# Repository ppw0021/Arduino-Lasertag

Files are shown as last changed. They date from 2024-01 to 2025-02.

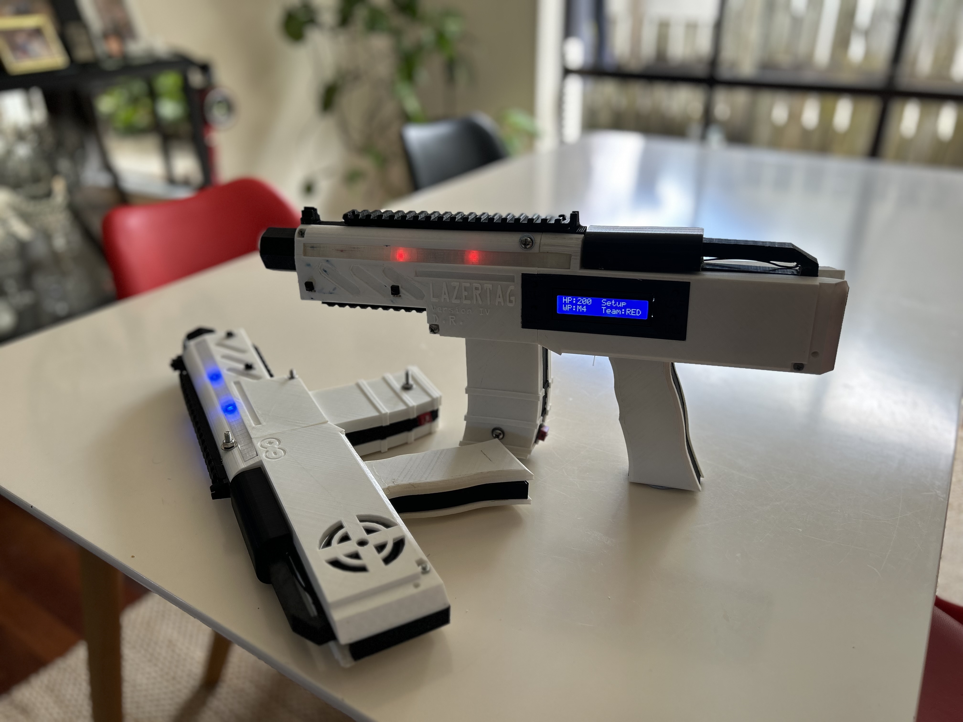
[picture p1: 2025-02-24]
Guns.jpg

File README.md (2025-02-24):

# DIY Arduino Lasertag

This is an Arduino powered Infrared laser tag set I created. It is powered using an Arduino Nano. The set has 6 primary functions and features such as, ammunition counter, hit-detection from other laser tag guns, IR data analysis, reloading button paired with a slider, LCD user interface and finally a play feedback subsystem as well as features such as 8 different weapons, filtration of teamfire and a health counter. This project scored me a spot at the ASB Brightsparks competition.

Guns

## 3D printed parts
Each laser tag gun consists of 13 3D printed parts. The guns structure uses a middle black frame which holds a majority of the electronic components and microcontroller, while 4 large shells cover both sides of the black frame.

Frame:

FrameRender

Exploded assembly:

FullRenderExploded

Frame with shells and accessories:

FullRender

As this was a long time and I did not know any better, I created the 3D models in SketchUp (🤮) and exported them as very very broken STLs. I used Netfabb to fix the models and make them manifold.
I recommend using Black, White and Clear PLA or ABS plastic at 0.1mm layer height for best results. 

## Electronics

The microcontroller for this project is an Arduino Nano with an ATmega328p chip onboard.
The following components are required for each laser gun:
- 1x IR LED  (For signal transmission)
- 1x 31MM biconvex lens 27MM focal point  (For straightening the IR light from the IR LED)
- 6x IR Receiver TSOP4838 DIP3  (For receiving transmissions from other laser guns)
- 1x i2c 16x2 LCD display modules  (For displaying UI to user)
- 1x YX5300 UART Serial MP3 player  (For playing sounds)
- 1x MicroSD card  (For storing sounds)
- 3x DC3v Button Vibrating Motors  (For providing haptic feedback)
- 6x push buttons  (For navigating UI and reload switches)
- 1x PAM8403 digital amplifier (For amplifying the audio signal from the MP3 Player)
  - 1x 4omh speaker
  - 1x 4.7uF capacitor
- 7x 1k ohm resistors (Various pulldown)
- 1x NPN transistor (For switching on and off the vibrating motors)

## Assembly of Electronics

The wiring and connections for each gun is shown below.

Layout

With the wiring and assembly completed, this is how each device looks.





## Biconvex lens

A biconvex lens is required to convert the dispersed light from the IR led into collimated light. (Basically straightening out the light rays) This is required so that the light behaves similarly to a 'bullet' and travels in a straight line, allowing for an accurate simulation.

lens with lines

## Code

```cpp
/***********************************************************/
//  Program made by Declan Ross
//  26,08,2018
//  V3.1
//
//
//    MP3:
//    sendSong(CMD_PLAY_W_VOL, 0x1E, 0x02);     Replace 0x02 with Hex MP3 name, use this for playing files
//                                              Also, 0x1E can be replaced with a volume Hex number (0-30)
//                                              0x1E=30
//
//
//    ammoQuota = checkAmmo(wpSL);              Use these 2 lines of code to refresh the display
//    lcdPrintPL(hpSL, ammoLeft, wpSL, tmSL);
//
//    ammoLeft=ammoQuota;                       Use this one to reload
//
//    Use pause() instead of delay() so that interupts will work
//
//
//    USE THE MAIN DIRECTORY FOR IMPORTANT TIMING ON THE SD CARD
//    MP3's IN A FOLDER TAKE LONGER TO EXECUTE
//
//
//    Use function pauseIR() instead of delays so that the arduino can recieve singals
//    and pause at the same time
//
//    pauseIR(500, tmSL, hpSL);
//
//    //USE THIS LINE TO CHECK IRIN SIGNAL
//    checkIRIN(tmSL, hpSL);
//
//
//
//
//
/***********************************************************/

/***********************************************************/
//For easy customisation change values
//
//
#define m4dmg 35
#define smgdmg 21
#define uspdmg 40
#define awpdmg 75
#define m4sdmg 30
#define smgsdmg 19
#define uspsdmg 38
#define awpsdmg 70

//MP3 custom lib
static int8_t Send_buf[8] = {0} ;
#define CMD_PLAY_W_INDEX 0X03
#define CMD_SET_VOLUME 0X06
#define CMD_SEL_DEV 0X09
#define DEV_TF 0X02
#define CMD_PLAY 0X0D
#define CMD_PAUSE 0X0E
#define CMD_SINGLE_CYCLE 0X19
#define SINGLE_CYCLE_ON 0X00
#define SINGLE_CYCLE_OFF 0X01
#define CMD_PLAY_W_VOL 0X22
#define CMD_PLAY_IN_FOLDER 0X0F

//Include The folowing Libraries
//LCD req
#include <LiquidCrystal_I2C.h>
#include <IRremote.h>
#include <SoftwareSerial.h>
#include <Wire.h>

//IR req
//Experimental

//Working
//#include <IRLibDecodeBase.h>
//#include <IRLibSendBase.h>
//#include <IRLib_P01_NEC.h>
//#include <IRLib_P02_Sony.h>
//#include <IRLib_HashRaw.h>  //Must be last protocol
//#include <IRLibCombo.h>
//#include <IRLibRecv.h>
//MP3 Req

//Define logical pins to words
#define fireTrigger 7
#define irIn 2
#define magReload 4
#define vMotor 5
#define lowHP 6
#define irOut 3
#define ARDUINO_RX A6
#define ARDUINO_TX 8
SoftwareSerial mySerial(ARDUINO_RX, ARDUINO_TX);
#define tmBluLED 9
#define tmRedLED 10
//#define fireMode 11
#define slideSW 12
#define hpSW A7
#define ST1LED 17
#define ST2LED 16
#define tmSW 15
#define wpSW 14
#define confSW 13

//Millis timer functionality
unsigned long startMillis;  //some global variables available anywhere in the program
unsigned long currentMillis;

//Set integers
int setConfirmed;
int displayCountdown;
boolean alive;
int timerBreak;
unsigned long pauseT;
unsigned long gunSound;
unsigned long hexCode;
int pauseTime;
boolean slideDone;
boolean oof;
int dmgM;
long unsigned longValue;

//Set button state variables
boolean rlST;
boolean sldST;
boolean trST;
boolean tmST;
boolean wpST;
int hpST;
boolean confST;
boolean slideST;
boolean btnPressed;

//Set selected state veriables
int tmSL;
int wpSL = 0;
int hpSL; //This also doubles as current hp

//Weapon variables
int ammoQuota;
int ammoLeft;

//Define others
//LiquidCrystal_I2C lcd(0x27, 2, 1, 0, 4, 5, 6, 7, 3, POSITIVE);
LiquidCrystal_I2C lcd(0x27,20,4);
IRrecv irrecv(2);
decode_results results;
IRsend irsend;

//IRrecv myReceiver(2);
//IRdecode myDecoder;
//IRsend mySender;

void setup() {
  startMillis = millis();
  pinMode(tmBluLED, OUTPUT);
  pinMode(tmRedLED, OUTPUT);   // start serial interface
  pinMode(ST1LED, OUTPUT);
  pinMode(ST2LED, OUTPUT);
  pinMode(vMotor, OUTPUT);
  pinMode(lowHP, OUTPUT);
  mySerial.begin(9600);
  pause(500);             // wait for init
  selectCommand(CMD_SEL_DEV, DEV_TF);   //select sd-card
  pause(500);         // wait for init
  lcd.begin(16, 2);
  pause(200);
  lcd.print("LAZERTAG beta3.1");
  lcd.setCursor(0, 1);
  lcd.print("Made by:Declan.R");
  pause(1000);
  lcd.clear();
  lcd.print("HP:     Setup   ");
  lcd.setCursor(0, 1);
  lcd.print("WP:     Team:   ");
  randomSeed(analogRead(6));
}

void loop() {
  while (setConfirmed == 0) {  //Setup code for setting variables, player cannot be hit and this should freeze when player clicks confirm.
    wpSL = wpSLfunc(wpSL);
    hpSL = hpSLfunc(hpSL);
    tmSL = tmSLfunc(tmSL);
    setConfirmed = confunc(setConfirmed);
  }

  if (displayCountdown == 0) {
    lcd.clear();
    lcd.print("Game starts in:");
    lcd.setCursor(7, 1);
    pause(200);
    lcd.print("3");
    sendSong(CMD_PLAY_IN_FOLDER, 0x02, 0x05);
    pause(400);
    lcd.setCursor(7, 1);
    lcd.print("2");
    sendSong(CMD_PLAY_IN_FOLDER, 0x02, 0x05);
    pause(400);
    lcd.setCursor(7, 1);
    lcd.print("1");
    sendSong(CMD_PLAY_IN_FOLDER, 0x02, 0x05);
    pause(400);
    lcd.setCursor(7, 1);
    lcd.print("GO!");
    sendSong(CMD_PLAY_IN_FOLDER, 0x02, 0x06);
    pause(400);
    displayCountdown = 1;
    ammoQuota = checkAmmo(wpSL);              //Use these 2 lines of code to refresh the screen
    ammoLeft = ammoQuota;
    lcdPrintPL(hpSL, ammoLeft, wpSL, tmSL);     //with the HP, TM, current AMMO and WP
    irrecv.enableIRIn();
  }
  while (alive == 0) {
    do {
      if (irrecv.decode(&results)) {        /// ADD THIS IF STATEMENT TO OTHER IR CHECKERS
        hpSL = checkIR(tmSL, hpSL, results.value);
        results.value = 0x00;
        if (hpSL == 0 or hpSL <= 0) {
          sendSong(CMD_PLAY_IN_FOLDER, 0x03, 0x02);
          deadLoop();
        }
        lcdUpdateHP(hpSL);
      }
      ammoQuota = checkAmmo(wpSL);
      trST = digitalRead(fireTrigger);
      if (trST == 1) {
        btnPressed = 1;
      }
      wpST = digitalRead(wpSW);
      if (wpST == 1) {
        btnPressed = 1;
      }
      rlST = digitalRead(magReload);
      if (rlST == 1) {
        btnPressed = 1;
      }
    } while (btnPressed == 0);
    if (wpST == 1) {
      wpSL = wpSLfunc2(wpSL);
      lcdPrintPL(hpSL, ammoLeft, wpSL, tmSL);
      ammoLeft = 0;
      lcd.setCursor(8, 0);
      lcd.print("RELOAD  ");
      btnPressed = 0;
    }
    if (rlST == 1) {
      lcd.setCursor(8, 0);
      lcd.print("RELOAD  ");
      lcd.setCursor(0, 1);
      lcd.print("Reloading       ");
      sendSong(CMD_PLAY_IN_FOLDER, 0x02, 0x07);   //play mag reload sound
      pause(70);
      digitalWrite(vMotor, HIGH);
      pause(150);
      if (irrecv.decode(&results)) {        /// ADD THIS IF STATEMENT TO OTHER IR CHECKERS
        hpSL = checkIR(tmSL, hpSL, results.value);
        results.value = 0x00;
        if (hpSL == 0 or hpSL <= 0) {
          sendSong(CMD_PLAY_IN_FOLDER, 0x03, 0x02);
          deadLoop();
        }
        lcdUpdateHP(hpSL);
      }
      digitalWrite(vMotor, LOW);
      pause(530);
      if (irrecv.decode(&results)) {        /// ADD THIS IF STATEMENT TO OTHER IR CHECKERS
        hpSL = checkIR(tmSL, hpSL, results.value);
        results.value = 0x00;
        if (hpSL == 0 or hpSL <= 0) {
          sendSong(CMD_PLAY_IN_FOLDER, 0x03, 0x02);
          deadLoop();
        }
        lcdUpdateHP(hpSL);
      }
      digitalWrite(vMotor, HIGH);
      pause(150);
      if (irrecv.decode(&results)) {        /// ADD THIS IF STATEMENT TO OTHER IR CHECKERS
        hpSL = checkIR(tmSL, hpSL, results.value);
        results.value = 0x00;
        if (hpSL == 0 or hpSL <= 0) {
          sendSong(CMD_PLAY_IN_FOLDER, 0x03, 0x02);
          deadLoop();
        }
        lcdUpdateHP(hpSL);
      }
      digitalWrite(vMotor, LOW);
      pause(500);
      if (irrecv.decode(&results)) {        /// ADD THIS IF STATEMENT TO OTHER IR CHECKERS
        hpSL = checkIR(tmSL, hpSL, results.value);
        results.value = 0x00;
        if (hpSL == 0 or hpSL <= 0) {
          sendSong(CMD_PLAY_IN_FOLDER, 0x03, 0x02);
          deadLoop();
        }
        lcdUpdateHP(hpSL);
      }
      slideDone = 0;
      while (slideDone == 0) {
        lcd.setCursor(0, 1);
        lcd.print("Slide to reload ");
        slideST = digitalRead(slideSW);
        if (irrecv.decode(&results)) {        /// ADD THIS IF STATEMENT TO OTHER IR CHECKERS
          hpSL = checkIR(tmSL, hpSL, results.value);
          results.value = 0x00;
          if (hpSL == 0 or hpSL <= 0) {
            sendSong(CMD_PLAY_IN_FOLDER, 0x03, 0x02);
            deadLoop();
          }
          lcdUpdateHP(hpSL);
        }
        if (slideST == 1) {
          sendSong(CMD_PLAY_IN_FOLDER, 0x02, 0x08);
          pause(50);
          lcdUpdateHP(hpSL);
          digitalWrite(vMotor, HIGH);
          pause(100);
          lcdUpdateHP(hpSL);
          digitalWrite(vMotor, LOW);
          pause(200);
          digitalWrite(vMotor, HIGH);
          pause(100);
          digitalWrite(vMotor, LOW);
          pause(200);
          lcdUpdateHP(hpSL);
          ammoLeft = ammoQuota;
          lcdPrintPL(hpSL, ammoLeft, wpSL, tmSL);
          slideDone = 1;
        }
      }
      btnPressed = 0;
    }
    if (trST == 1) { //Firing mechanism
      if (ammoLeft >= 1) {
        gunSound = sendMP3(wpSL);
        sendSong(CMD_PLAY_IN_FOLDER, 0x04, gunSound);   //use a search function here to find the mp3 name
        digitalWrite(ST1LED, HIGH);
        ammoLeft = ammoLeft - 1;
        lcdUpdate(ammoLeft);
        lcdUpdateHP(hpSL);
        if (irrecv.decode(&results)) {        /// ADD THIS IF STATEMENT TO OTHER IR CHECKERS
          hpSL = checkIR(tmSL, hpSL, results.value);
          results.value = 0x00;
          if (hpSL == 0 or hpSL <= 0) {
            sendSong(CMD_PLAY_IN_FOLDER, 0x03, 0x02);
            deadLoop();
          }
          lcdUpdateHP(hpSL);
        }
        digitalWrite(vMotor, HIGH);
        pauseTime = frCheck(wpSL);
        hexCode = sendIRCODE(tmSL, wpSL);
        irsend.sendNEC(hexCode, 16);
        irrecv.enableIRIn();
        irrecv.resume();
        pause(pauseTime);
        digitalWrite(lowHP, LOW);
        digitalWrite(vMotor, LOW);
        if (irrecv.decode(&results)) {        /// ADD THIS ItF STATEMENT TO OTHER IR CHECKERS
          hpSL = checkIR(tmSL, hpSL, results.value);
          results.value = 0x00;
          if (hpSL == 0 or hpSL <= 0) {
            sendSong(CMD_PLAY_IN_FOLDER, 0x03, 0x02);
            deadLoop();
          }
          lcdUpdateHP(hpSL);
        }
        digitalWrite(vMotor, LOW);
        digitalWrite(ST1LED, LOW);
        if (wpSL == awpdmg or wpSL == awpsdmg) {
          pause(pauseTime);
          lcd.setCursor(0, 1);
          lcd.print("Slide to load   ");
          digitalWrite(ST1LED, LOW);
          slideST = digitalRead(slideSW);
          while (slideST == 0) {
            if (irrecv.decode(&results)) {        /// ADD THIS IF STATEMENT TO OTHER IR CHECKERS
              hpSL = checkIR(tmSL, hpSL, results.value);
              results.value = 0x00;
              if (hpSL == 0 or hpSL <= 0) {
                sendSong(CMD_PLAY_IN_FOLDER, 0x03, 0x02);
                deadLoop();
              }
              lcdUpdateHP(hpSL);
            }
            slideST = digitalRead(slideSW);
          }
          sendSong(CMD_PLAY_IN_FOLDER, 0x02, 0x08);
          lcdPrintPL(hpSL, ammoLeft, wpSL, tmSL);
          lcdUpdateHP(hpSL);
        }
        else if (wpSL == uspdmg or wpSL == uspsdmg) {
          digitalWrite(ST1LED, LOW);
          trST = digitalRead(fireTrigger);
          while (trST == 1) {
            trST = digitalRead(fireTrigger);
            if (irrecv.decode(&results)) {        /// ADD THIS IF STATEMENT TO OTHER IR CHECKERS
              hpSL = checkIR(tmSL, hpSL, results.value);
              results.value = 0x00;
              if (hpSL == 0 or hpSL <= 0) {
                sendSong(CMD_PLAY_IN_FOLDER, 0x03, 0x02);
                deadLoop();
              }
              lcdUpdateHP(hpSL);
            }
          }
        }
        else {
          if (irrecv.decode(&results)) {        /// ADD THIS IF STATEMENT TO OTHER IR CHECKERS
            hpSL = checkIR(tmSL, hpSL, results.value);
            results.value = 0x00;
            if (hpSL == 0 or hpSL <= 0) {
              sendSong(CMD_PLAY_IN_FOLDER, 0x03, 0x02);
              deadLoop();
            }
            lcdUpdateHP(hpSL);
          }
        }

        //
      }
      else if (ammoLeft == 0) {
        sendSong(CMD_PLAY_IN_FOLDER, 0x03, 0x01);
        lcd.setCursor(8, 0);
        lcd.print("RELOAD  ");
        pauseTime = frCheck(wpSL);
        pause(pauseTime);
        if (irrecv.decode(&results)) {        /// ADD THIS IF STATEMENT TO OTHER IR CHECKERS
          hpSL = checkIR(tmSL, hpSL, results.value);
          results.value = 0x00;
          if (hpSL == 0 or hpSL <= 0) {
            sendSong(CMD_PLAY_IN_FOLDER, 0x03, 0x02);
            deadLoop();
          }
          lcdUpdateHP(hpSL);
        }
        pause(220);
        if (irrecv.decode(&results)) {        /// ADD THIS IF STATEMENT TO OTHER IR CHECKERS
          hpSL = checkIR(tmSL, hpSL, results.value);
          results.value = 0x00;
          if (hpSL == 0 or hpSL <= 0) {
            sendSong(CMD_PLAY_IN_FOLDER, 0x03, 0x02);
            deadLoop();
          }
          lcdUpdateHP(hpSL);
        }//to simulate the delay of the mySend.send(); command
        trST = digitalRead(fireTrigger);

      }
      btnPressed = 0;
    }
  }//Main code can start here as the setup statement will now be completly ignored
}

int hpSLfunc (int hp) { //HP SELECT FUNCTION
  hpST = analogRead(hpSW);
  if (hp == 0) {
    hp = 100;
    lcd.setCursor(3, 0);
    lcd.print("100");
    return hp;
  }
  if (hpST >= (900)) {
    lcd.setCursor(3, 0);
    sendSong(CMD_PLAY_IN_FOLDER, 0x02, 0x03);
    if (hp == 1) {
      hp = 100;
      lcd.print("100");
      pause(500);
      return hp;
    }
    if (hp == 100) {
      hp = 75;
      lcd.print("75 ");
      pause(500);
      return hp;
    }
    if (hp == 75) {
      hp = 50;
      lcd.print("50 ");
      pause(500);
      return hp;
    }
    if (hp == 50) {
      hp = 25;
      lcd.print("25 ");
      pause(500);
      return hp;
    }
    if (hp == 25) {
      hp = 1;
      lcd.print("1  ");
      pause(500);
      return hp;
    }
  }
}

int confunc(int c) { //CONFIRM SW FUNCTION
  confST = digitalRead(confSW);
  if (confST == 1) {
    c = 1;
    return c;
  }
  if (confST == 0) {
    c = 0;
    return c;
  }
}

int wpSLfunc(int wp) { //WEAPON SW FUNCTION
  wpST = digitalRead(wpSW);
  if (wp == 0) {
    lcd.setCursor(3, 1);
    lcd.print("M4  ");
    wp = m4dmg;
    return wp;
  }
  if (wpST == 1) {
    lcd.setCursor(3, 1);
    sendSong(CMD_PLAY_IN_FOLDER, 0x02, 0x02);
    if (wp == awpsdmg) {
      wp = m4dmg;
      lcd.print("M4  ");
      pause(500);
      return wp;
    }
    if (wp == m4dmg) {
      wp = smgdmg;
      lcd.print("SMG ");
      pause(500);
      return wp;
    }
    if (wp == smgdmg) {
      wp = uspdmg;
      lcd.print("USP ");
      pause(500);
      return wp;
    }
    if (wp == uspdmg) {
      wp = awpdmg;
      lcd.print("AWP ");
      pause(500);
      return wp;
    }
    if (wp == awpdmg) {
      wp = m4sdmg;
      lcd.print("M4s ");
      pause(500);
      return wp;
    }
    if (wp == m4sdmg) {
      wp = smgsdmg;
      lcd.print("SMGs");
      pause(500);
      return wp;
    }
    if (wp == smgsdmg) {
      wp = uspsdmg;
      lcd.print("USPs");
      pause(500);
      return wp;
    }
    if (wp == uspsdmg) {
      wp = awpsdmg;
      lcd.print("AWPs");
      pause(500);
      return wp;
    }
  }
}

int tmSLfunc(int tm) {
  tmST = digitalRead(tmSW);
  if (tm == 0) {
    tm = 2;
    lcd.setCursor(13, 1);
    lcd.print("RED");
    digitalWrite(tmRedLED, HIGH);
    digitalWrite(tmBluLED, LOW);
    pause(500);
    return tm;
  }
  if (tmST == 1) {
    sendSong(CMD_PLAY_IN_FOLDER, 0x02, 0x04);
    lcd.setCursor(13, 1);
    if (tm == 3) {
      lcd.print("BLU");
      tm = 1;
      digitalWrite(tmRedLED, LOW);
      digitalWrite(tmBluLED, HIGH);
      pause(500);
      return tm;
    }
    if (tm == 1) {
      tm = 2;
      lcd.print("RED");
      digitalWrite(tmRedLED, HIGH);
      digitalWrite(tmBluLED, LOW);
      pause(500);
      return tm;
    }
    if (tm == 2) {
      tm = 3;
      lcd.print("FFA");
      digitalWrite(tmRedLED, HIGH);
      digitalWrite(tmBluLED, HIGH);
      pause(500);
      return tm;
    }
  }
}

void lcdPrintPL (int hp, int am, int wp, int tm) {
  lcd.clear();
  lcd.print("HP:    ");
  lcd.setCursor(3, 0);
  lcd.print(hp);
  lcd.setCursor(8, 0);
  lcd.print("Ammo:");
  lcd.print(am);
  lcd.setCursor(0, 1);
  lcd.print("WP:");
  if (wp == m4dmg) {
    lcd.print("M4");
  }
  if (wp == smgdmg) {
    lcd.print("SMG");
  }
  if (wp == uspdmg) {
    lcd.print("USP");
  }
  if (wp == awpdmg) {
    lcd.print("AWP");
  }
  if (wp == m4sdmg) {
    lcd.print("M4s");
  }
  if (wp == smgsdmg) {
    lcd.print("SMGs");
  }
  if (wp == uspsdmg) {
    lcd.print("USPs");
  }
  if (wp == awpsdmg) {
    lcd.print("AWPs");
  }
  lcd.setCursor(8, 1);
  lcd.print("Team:");
  if (tm == 2) {
    lcd.print("RED");
  }
  if (tm == 1) {
    lcd.print("BLU");
  }
  if (tm == 3) {
    lcd.print("FFA");
  }
}

int checkAmmo (int wp) {
  int am;
  if (wp == m4dmg) {
    am = 31;
    return am;
  }
  if (wp == smgdmg) {
    am = 41;
    return am;
  }
  if (wp == uspdmg) {
    am = 16;
    return am;
  }
  if (wp == awpdmg) {
    am = 6;
    return am;
  }
  if (wp == m4sdmg) {
    am = 31;
    return am;
  }
  if (wp == smgsdmg) {
    am = 41;
    return am;
  }
  if (wp == uspsdmg) {
    am = 16;
    return am;
  }
  if (wp == awpsdmg) {
    am = 6;
    return am;
  }
}

int selectCommand(int8_t command, int16_t dat)
{
  pause(20);
  Send_buf[0] = 0x7e; //starting byte
  Send_buf[1] = 0xff; //version
  Send_buf[2] = 0x06; //the number of bytes of the command without starting byte and ending byte
  Send_buf[3] = 0x01; //
  Send_buf[4] = 0x00;//0x00 = no feedback, 0x01 = feedback
  Send_buf[5] = (int8_t)(dat >> 8);//datah
  Send_buf[6] = (int8_t)(dat); //datal
  Send_buf[7] = 0xef; //ending byte
  for (uint8_t i = 0; i < 8; i++) //
  {
    mySerial.write(Send_buf[i]) ;
  }
}

int sendSong(int8_t command, int16_t dat, int16_t dat2)
{
  pause(20);
  Send_buf[0] = 0x7e; //starting byte
  Send_buf[1] = 0xff; //version
  Send_buf[2] = 0x06; //the number of bytes of the command without starting byte and ending byte
  Send_buf[3] = command; //
  Send_buf[4] = 0x00;//0x00 = no feedback, 0x01 = feedback
  Send_buf[5] = (dat);//datah
  Send_buf[6] = (dat2); //datal
  Send_buf[7] = 0xef; //ending byte
  for (uint8_t i = 0; i < 8; i++) //
  {
    mySerial.write(Send_buf[i]) ;
  }
}

void pause(unsigned long period) { //pause() replacing delay() function by using a simple millis() function
  do {
    currentMillis = millis();
    //add a function here that repeatabily checks the if there is an IR signal in, and if there is (and confirmed == 1) and it is not corrupt
    //then goto a function that checks the team and if it a different team subract Hp and display onscreen
    if (currentMillis - startMillis >= period)
    {
      startMillis = currentMillis;
      return;
    }
  } while (timerBreak == 0);
}

int wpSLfunc2(int wp) { //WEAPON SW FUNCTION
  sendSong(CMD_PLAY_IN_FOLDER, 0x02, 0x02);
  if (wp == awpsdmg) {
    wp = m4dmg;
    pause(200);
    return wp;
  }
  if (wp == m4dmg) {
    wp = smgdmg;
    pause(200);
    return wp;
  }
  if (wp == smgdmg) {
    wp = uspdmg;
    pause(200);
    return wp;
  }
  if (wp == uspdmg) {
    wp = awpdmg;
    pause(200);
    return wp;
  }
  if (wp == awpdmg) {
    wp = m4sdmg;
    pause(200);
    return wp;
  }
  if (wp == m4sdmg) {
    wp = smgsdmg;
    pause(200);
    return wp;
  }
  if (wp == smgsdmg) {
    wp = uspsdmg;
    pause(200);
    return wp;
  }
  if (wp == uspsdmg) {
    wp = awpsdmg;
    pause(200);
    return wp;
  }
}

unsigned long sendIRCODE(int tm, int wp) {       //Send signal about shot data
  if (tm == 3) {                      //FFA team wp check
    if (wp == m4dmg) {
      return 0x1F;
    }
    if (wp == smgdmg) {
      return 0x20;
    }
    if (wp == uspdmg) {
      return 0x21;
    }
    if (wp == awpdmg) {
      return 0x22;
    }
    if (wp == m4sdmg) {
      return 0x23;
    }
    if (wp == smgsdmg) {
      return 0x24;
    }
    if (wp == uspsdmg) {
      return 0x25;
    }
    if (wp == awpsdmg) {
      return 0x26;
    }
  }
  if (tm == 1) {                      //BLU team wp check
    if (wp == m4dmg) {
      return 0x29;
    }
    if (wp == smgdmg) {
      return 0x2A;
    }
    if (wp == uspdmg) {
      return 0x2B;
    }
    if (wp == awpdmg) {
      return 0x2C;
    }
    if (wp == m4sdmg) {
      return 0x2D;
    }
    if (wp == smgsdmg) {
      return 0x2E;
    }
    if (wp == uspsdmg) {
      return 0x2F;
    }
    if (wp == awpsdmg) {
      return 0x30;
    }
  }
  if (tm == 2) {                      //RED team wp check
    if (wp == m4dmg) {
      return 0x33;
    }
    if (wp == smgdmg) {
      return 0x34;
    }
    if (wp == uspdmg) {
      return 0x35;
    }
    if (wp == awpdmg) {
      return 0x36;
    }
    if (wp == m4sdmg) {
      return 0x37;
    }
    if (wp == smgsdmg) {
      return 0x38;
    }
    if (wp == uspsdmg) {
      return 0x39;
    }
    if (wp == awpsdmg) {
      return 0x3A;
    }
  }
}

unsigned long sendMP3(int wp) {       //Send MP3 hex sound file name
  if (wp == m4dmg) {
    return 0x04;
  }
  if (wp == smgdmg) {
    return 0x01;
  }
  if (wp == uspdmg) {
    return 0x03;
  }
  if (wp == awpdmg) {
    return 0x05;
  }
  if (wp == m4sdmg) {
    return 0x02;
  }
  if (wp == smgsdmg) {
    return 0x02;
  }
  if (wp == uspsdmg) {
    return 0x02;
  }
  if (wp == awpsdmg) {
    return 0x02;
  }

}

int frCheck(int wp) {
  int fr;
  if (wp == m4dmg or wp == m4sdmg) {
    fr = random(70, 110);
    return fr;
  }
  if (wp == smgdmg or wp == smgsdmg) {
    fr = random(40, 70);
    return fr;
  }
  if (wp == uspdmg or wp == uspsdmg) {
    return 100;
  }
  if (wp == awpdmg or wp == awpsdmg) {
    //execute function here for timing
    return 1000 ;
  }
}

void lcdUpdate(int am) {
  lcd.setCursor(8, 0);
  lcd.print("Ammo:  ");
  lcd.setCursor(13, 0);
  lcd.print(am);
}

void lcdUpdateHP(int hp) {
  lcd.setCursor(0, 0);
  lcd.print("HP:    ");
  lcd.setCursor(3, 0);
  lcd.print(hp);
}

int checkIR(int tm, int hp, unsigned long res) {
  int dmg;
  longValue = res, HEX;
  digitalWrite(lowHP, HIGH);
  if (longValue == 0x1F) {         //FFA team wp check
    hp = hp - m4dmg;
    sendSong(CMD_PLAY_IN_FOLDER, 0x03, 0x03);
    irrecv.resume();
    return hp;
  }
  else if (longValue == 0x20) {
    hp = hp - smgdmg;
    sendSong(CMD_PLAY_IN_FOLDER, 0x03, 0x03);
    irrecv.resume();
    return hp;
  }
  else if (longValue == 0x21) {
    hp = hp - smgdmg;
    sendSong(CMD_PLAY_IN_FOLDER, 0x03, 0x03);
    irrecv.resume();
    return hp;
  }
  else if (longValue == 0x22) {
    hp = hp - awpdmg;
    sendSong(CMD_PLAY_IN_FOLDER, 0x03, 0x03);
    irrecv.resume();
    return hp;
  }
  else if (longValue == 0x23) {
    hp = hp - m4sdmg;
    sendSong(CMD_PLAY_IN_FOLDER, 0x03, 0x03);
    irrecv.resume();
    return hp;
  }
  else if (longValue == 0x24) {
    hp = hp - smgsdmg;
    sendSong(CMD_PLAY_IN_FOLDER, 0x03, 0x03);
    irrecv.resume();
    return hp;
  }
  else if (longValue == 0x25) {
    hp = hp - uspsdmg;
    sendSong(CMD_PLAY_IN_FOLDER, 0x03, 0x03);
    irrecv.resume();
    return hp;
  }
  else if (longValue == 0x26) {
    hp = hp - awpsdmg;
    sendSong(CMD_PLAY_IN_FOLDER, 0x03, 0x03);
    irrecv.resume();
    return hp;
  }
  //BLU team wp check

  else if (longValue == 0x29) {    //BLU

    irrecv.resume();
    if (tm == 1) {
      digitalWrite(lowHP, LOW);
      return hp;
    }
    hp = hp - m4dmg;
    sendSong(CMD_PLAY_IN_FOLDER, 0x03, 0x03);
    return hp;
  }
  else if (longValue == 0x2A) {

    irrecv.resume();
    if (tm == 1) {
      digitalWrite(lowHP, LOW);
      return hp;
    }
    hp = hp - smgdmg;
    sendSong(CMD_PLAY_IN_FOLDER, 0x03, 0x03);
    return hp;
  }
  else if (longValue == 0x2B) {

    irrecv.resume();
    if (tm == 1) {
      digitalWrite(lowHP, LOW);
      return hp;
    }
    hp = hp - uspdmg;
    sendSong(CMD_PLAY_IN_FOLDER, 0x03, 0x03);
    return hp;
  }
  else if (longValue == 0x2C) {

    irrecv.resume();
    if (tm == 1) {
      digitalWrite(lowHP, LOW);
      return hp;
    }
    hp = hp - awpdmg;
    sendSong(CMD_PLAY_IN_FOLDER, 0x03, 0x03);
    return hp;
  }
  else if (longValue == 0x2D) {

    irrecv.resume();
    if (tm == 1) {
      digitalWrite(lowHP, LOW);
      return hp;
    }
    hp = hp - m4sdmg;
    sendSong(CMD_PLAY_IN_FOLDER, 0x03, 0x03);
    return hp;
  }
  else if (longValue == 0x2E) {

    irrecv.resume();
    if (tm == 1) {
      digitalWrite(lowHP, LOW);
      return hp;
    }
    hp = hp - smgsdmg;
    sendSong(CMD_PLAY_IN_FOLDER, 0x03, 0x03);
    return hp;
  }
  else if (longValue == 0x2F) {

    irrecv.resume();
    if (tm == 1) {
      digitalWrite(lowHP, LOW);
      return hp;
    }
    hp = hp - uspsdmg;
    sendSong(CMD_PLAY_IN_FOLDER, 0x03, 0x03);
    return hp;
  }
  else if (longValue == 0x30) {

    irrecv.resume();
    if (tm == 1) {
      digitalWrite(lowHP, LOW);
      return hp;
    }
    hp = hp - awpsdmg;
    sendSong(CMD_PLAY_IN_FOLDER, 0x03, 0x03);
    return hp;
  }
  //RED team wp check
  else if (longValue == 0x33) {     //RED

    irrecv.resume();
    if (tm == 2) {
      digitalWrite(lowHP, LOW);
      return hp;
    }
    hp = hp - m4dmg;
    sendSong(CMD_PLAY_IN_FOLDER, 0x03, 0x03);
    return hp;
  }
  else if (longValue == 0x34) {

    irrecv.resume();
    if (tm == 2) {
      digitalWrite(lowHP, LOW);
      return hp;
    }
    hp = hp - smgdmg;
    sendSong(CMD_PLAY_IN_FOLDER, 0x03, 0x03);
    return hp;
  }
  else if (longValue == 0x35) {

    irrecv.resume();
    if (tm == 2) {
      digitalWrite(lowHP, LOW);
      return hp;
    }
    hp = hp - smgdmg;
    sendSong(CMD_PLAY_IN_FOLDER, 0x03, 0x03);
    return hp;
  }
  else if (longValue == 0x36) {

    irrecv.resume();
    if (tm == 2) {
      digitalWrite(lowHP, LOW);
      return hp;
    }
    hp = hp - awpdmg;
    sendSong(CMD_PLAY_IN_FOLDER, 0x03, 0x03);
    return hp;
  }
  else if (longValue == 0x37) {

    irrecv.resume();
    if (tm == 2) {
      digitalWrite(lowHP, LOW);
      return hp;
    }
    hp = hp - m4sdmg;
    sendSong(CMD_PLAY_IN_FOLDER, 0x03, 0x03);
    return hp;
  }
  else if (longValue == 0x38) {

    irrecv.resume();
    if (tm == 2) {
      digitalWrite(lowHP, LOW);
      return hp;
    }
    hp = hp - smgsdmg;
    sendSong(CMD_PLAY_IN_FOLDER, 0x03, 0x03);
    return hp;
  }
  else if (longValue == 0x39) {

    irrecv.resume();
    if (tm == 2) {
      digitalWrite(lowHP, LOW);
      return hp;
    }
    hp = hp - uspsdmg;
    sendSong(CMD_PLAY_IN_FOLDER, 0x03, 0x03);
    return hp;
  }
  else if (longValue == 0x3A) {

    irrecv.resume();
    if (tm == 2) {
      digitalWrite(lowHP, LOW);
      return hp;
    }
    hp = hp - awpsdmg;
    sendSong(CMD_PLAY_IN_FOLDER, 0x03, 0x03);
    return hp;
  }
  else {
    irrecv.resume();
    digitalWrite(lowHP, LOW);
    return hp;
  }
}

void deadLoop() {
  digitalWrite(vMotor, LOW);
  digitalWrite(lowHP, HIGH);
  digitalWrite(ST1LED, HIGH);
  lcd.clear();
  lcd.print("GGWP!");
  lcd.setCursor(0, 1);
  lcd.print("You are dead ):");
  do {
    digitalWrite(tmRedLED, HIGH);
    digitalWrite(tmBluLED, HIGH);
    pause(300);
    digitalWrite(tmRedLED, LOW);
    digitalWrite(tmBluLED, LOW);
    pause(300);
  } while (oof == 0);
}

/*void checkIRIN (int tm, int hp) {
  if (irrecv.decode(&results)) {        /// ADD THIS IF STATEMENT TO OTHER IR CHECKERS
    hp = checkIR(tm, hp);
    irrecv.resume();
    sendSong(CMD_PLAY_IN_FOLDER, 0x03, 0x02);
    if (hp == 0 or hp <= 0) {
      sendSong(CMD_PLAY_IN_FOLDER, 0x03, 0x02);
      deadLoop();
    }
    lcdUpdateHP(hpSL);
  }
  }*/

```

## Version History

* 1.0
    * Initial Release

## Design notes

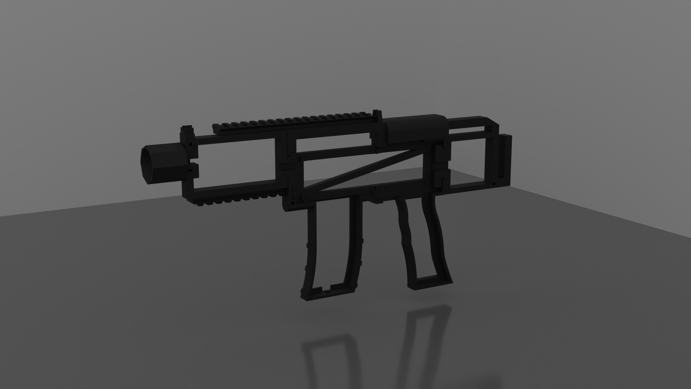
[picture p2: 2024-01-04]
FrameRender.png

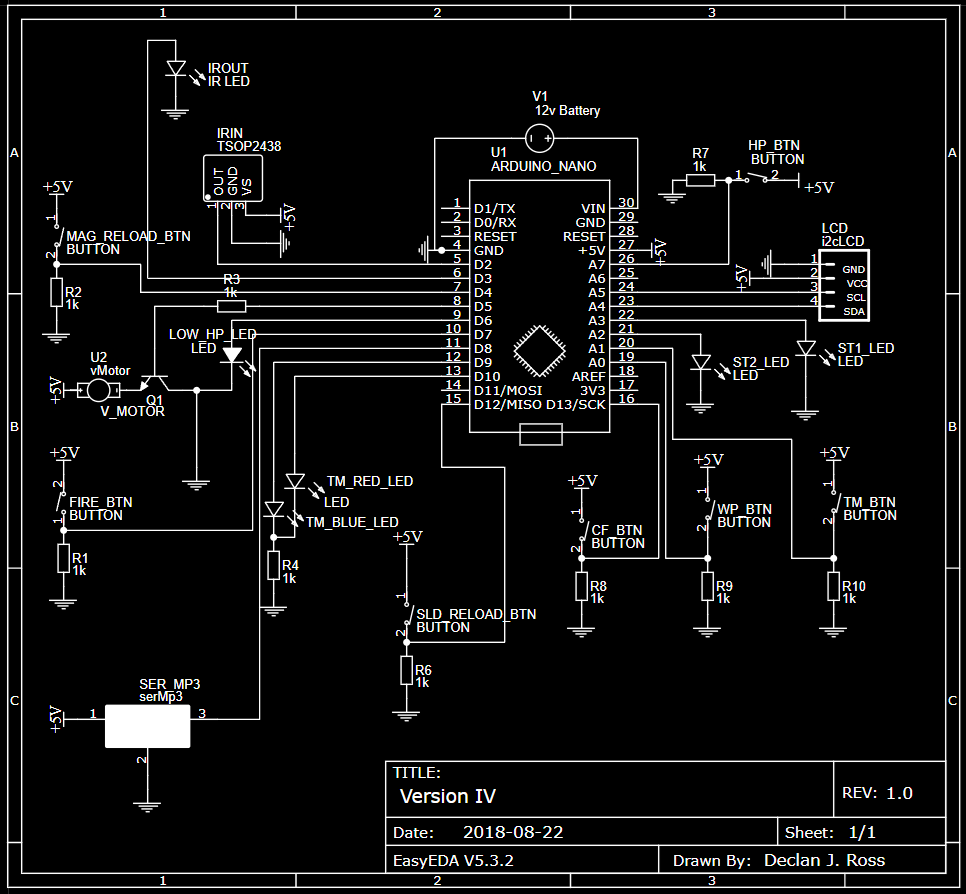
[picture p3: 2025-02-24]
Layout.png

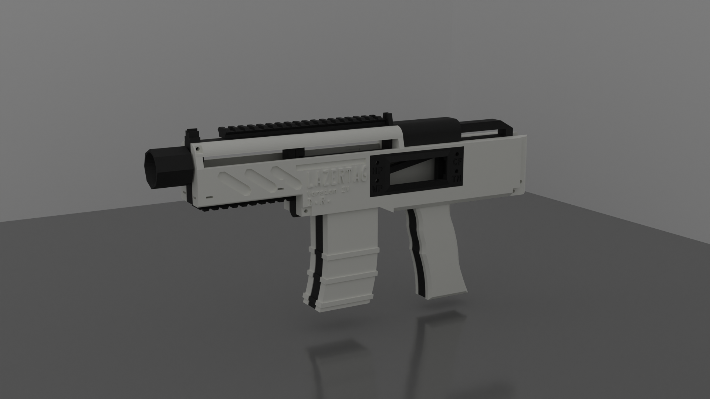
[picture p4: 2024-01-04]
FullRender.png

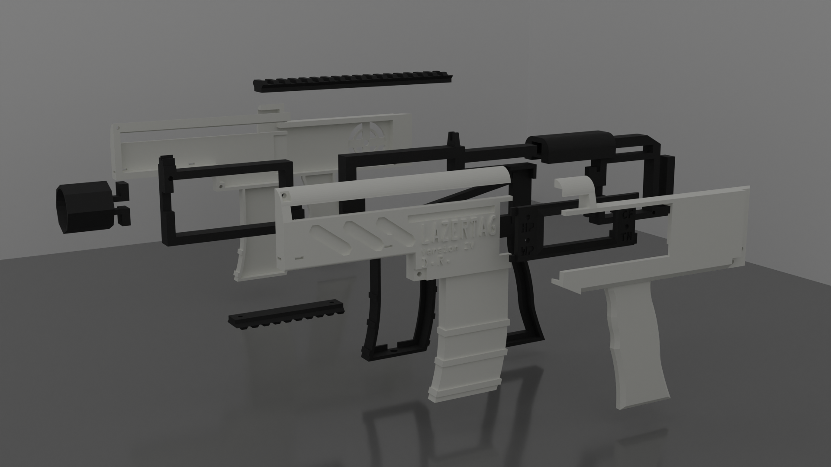
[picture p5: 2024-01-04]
FullRenderExploded.png

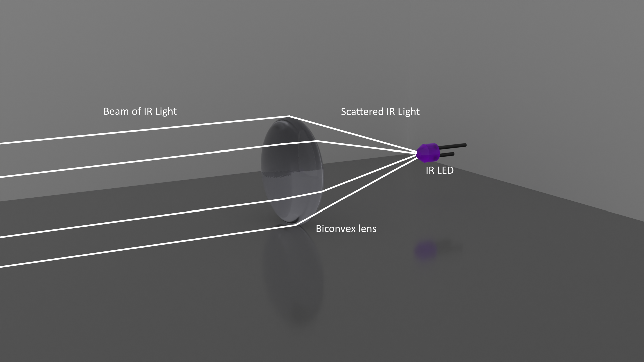
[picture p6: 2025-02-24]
lens with lines.png

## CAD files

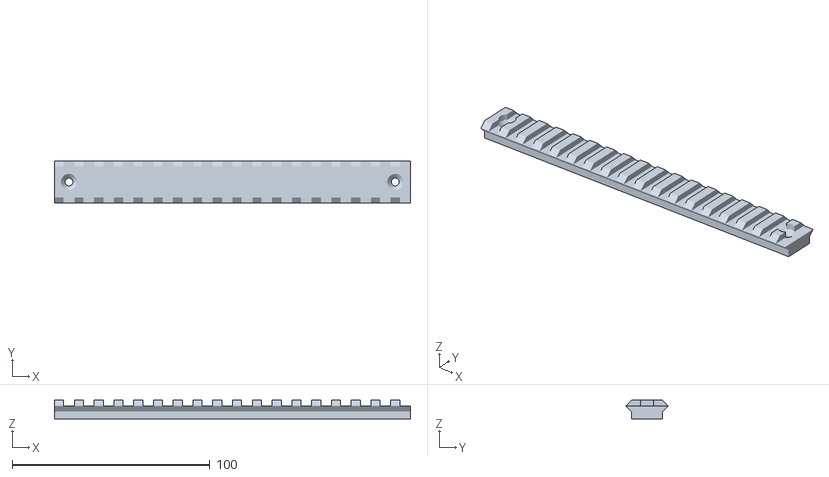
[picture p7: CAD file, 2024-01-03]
3D Models/Finished 3D Models/Black Parts/top_rail.stl
180.0 x 21.2 x 9.40

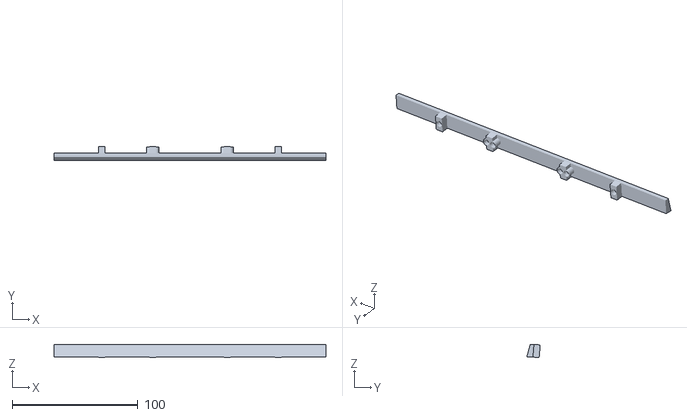
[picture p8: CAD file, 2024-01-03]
3D Models/Finished 3D Models/Clear Parts/led_strip.stl
216.0 x 10.8 x 10.6

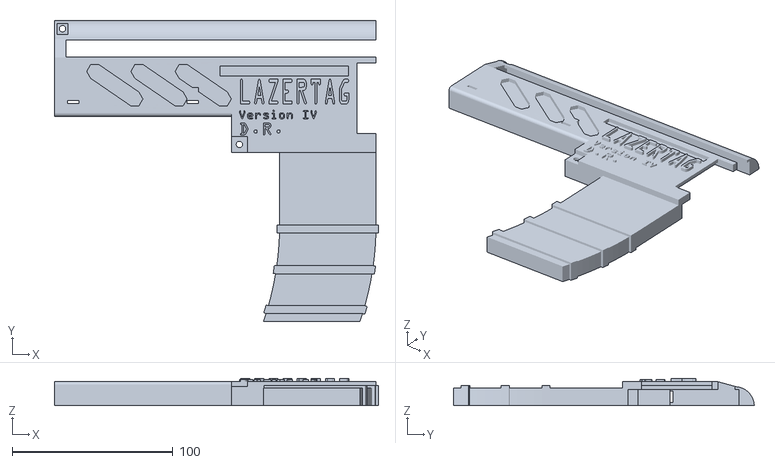
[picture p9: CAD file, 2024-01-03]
3D Models/Finished 3D Models/White Parts/front_left_cover.stl
201.5 x 187.0 x 17.1

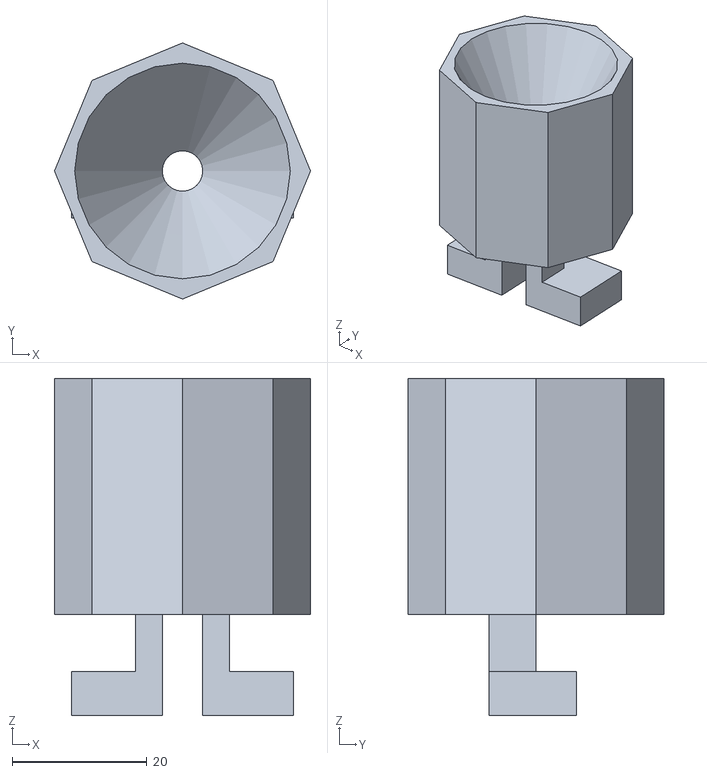
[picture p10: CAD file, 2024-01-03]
3D Models/Finished 3D Models/Black Parts/ir_out_housing.stl
38.0 x 38.0 x 50.0

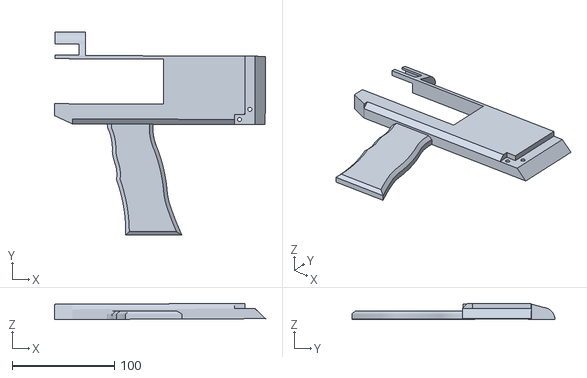
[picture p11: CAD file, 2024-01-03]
3D Models/Finished 3D Models/White Parts/rear_left_cover.stl
206.5 x 198.9 x 15.8

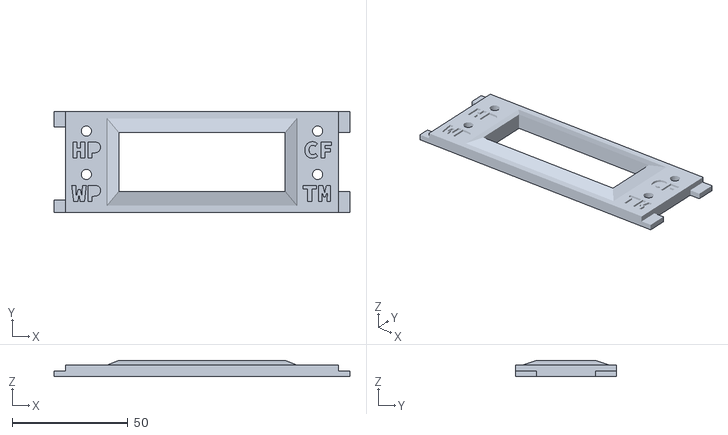
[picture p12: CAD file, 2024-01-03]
3D Models/Finished 3D Models/Black Parts/lcd_bezel.stl
128.0 x 43.5 x 7.00

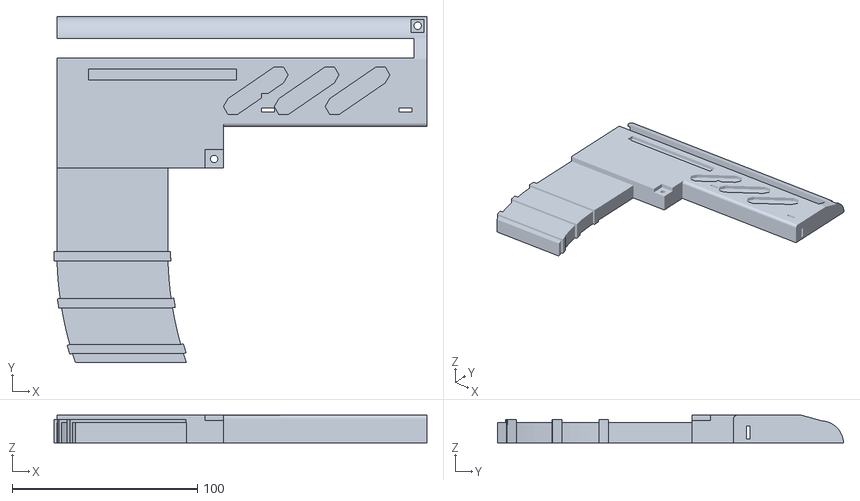
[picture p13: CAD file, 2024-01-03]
3D Models/Finished 3D Models/White Parts/front_right_cover.stl
201.5 x 187.0 x 15.0

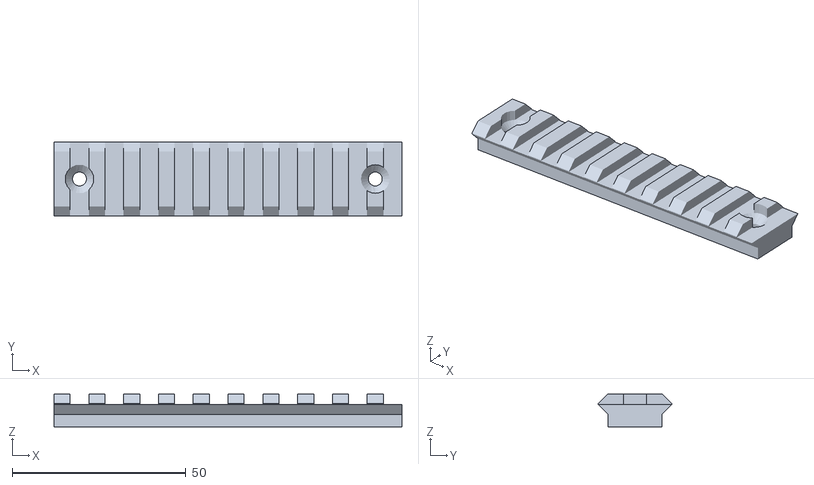
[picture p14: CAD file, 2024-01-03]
3D Models/Finished 3D Models/Black Parts/bottom_rail.stl
100.0 x 21.2 x 9.40

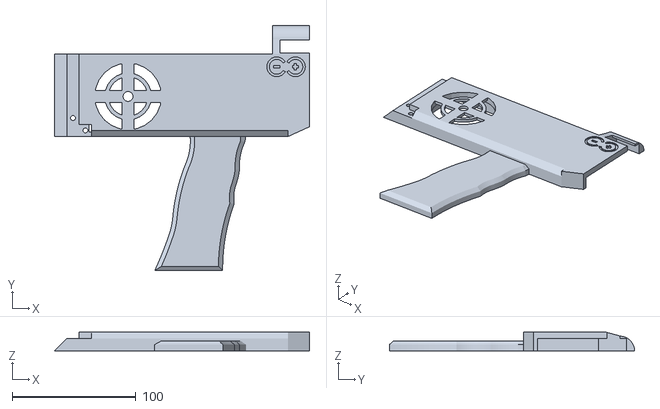
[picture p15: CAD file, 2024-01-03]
3D Models/Finished 3D Models/White Parts/rear_right_cover.stl
206.2 x 198.4 x 15.0

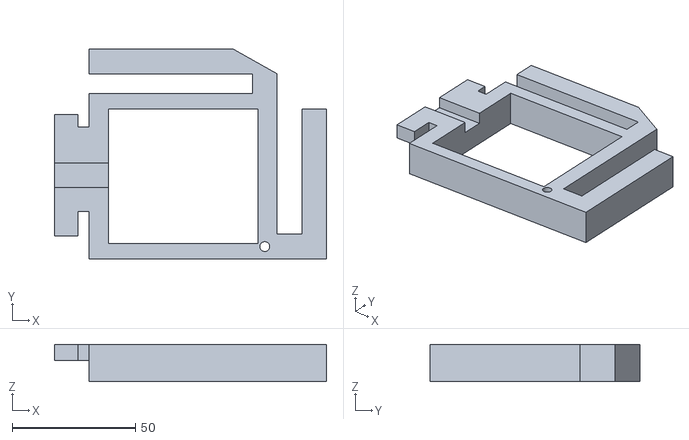
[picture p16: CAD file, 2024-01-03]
3D Models/Finished 3D Models/Black Parts/frame_rear.stl
110.2 x 85.0 x 15.0

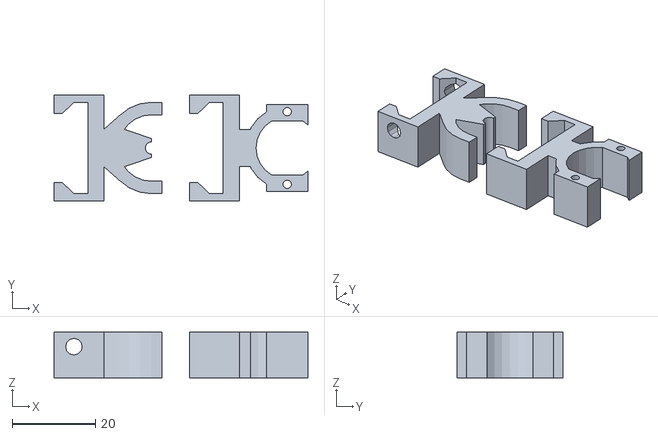
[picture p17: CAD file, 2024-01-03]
3D Models/Finished 3D Models/Black Parts/sights.stl
61.1 x 25.6 x 11.0

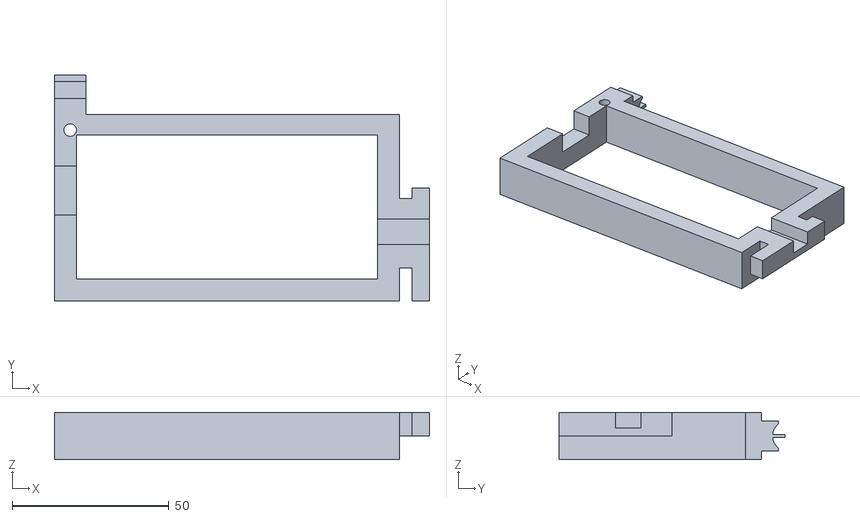
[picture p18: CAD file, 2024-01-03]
3D Models/Finished 3D Models/Black Parts/frame_front.stl
119.5 x 72.1 x 15.0

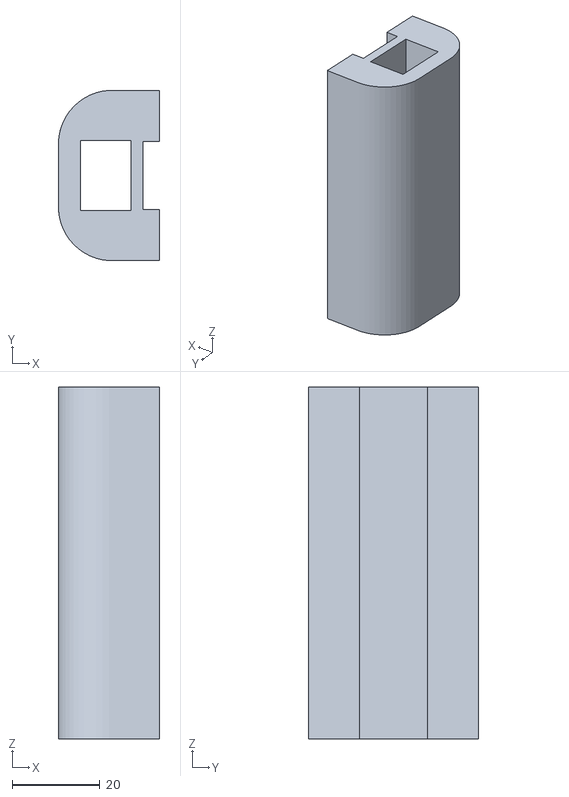
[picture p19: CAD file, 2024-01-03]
3D Models/Finished 3D Models/Black Parts/slider.stl
23.0 x 38.7 x 80.0

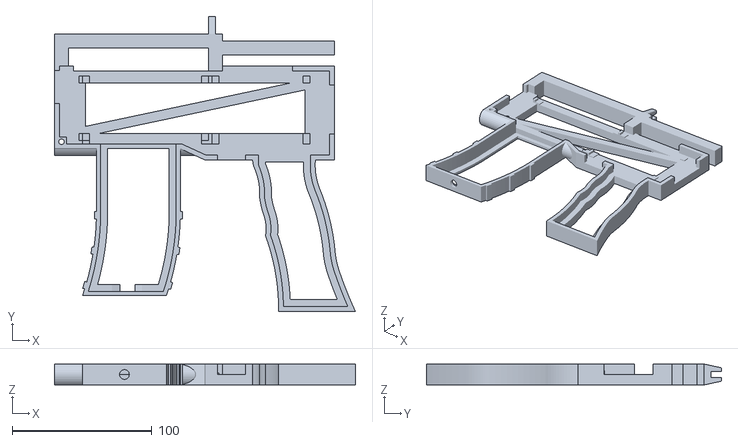
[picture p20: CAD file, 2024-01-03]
3D Models/Finished 3D Models/Black Parts/frame_middle.stl
215.2 x 211.0 x 15.0

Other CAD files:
3D Models/Finished 3D Models/Black Parts/sights_round.stl
3D Models/Finished 3D Models/Black Parts/stock.stl
3D Models/SketchUp files/IR - Casing.skp
3D Models/SketchUp files/LCD - bezel.skp
Stage.blend

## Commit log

2024-01-03 Added main and Sketchup files
    [IR - Casing.skp, LCD - bezel.skp]
2024-01-03 Added audio, 3D models and code
    [bottom_rail.stl, frame_front.stl, frame_middle.stl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]
2024-01-04 Added Photos
    [Stage.blend]
